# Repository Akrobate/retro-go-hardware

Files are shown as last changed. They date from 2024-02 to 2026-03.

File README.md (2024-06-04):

# retro-go-hardware

## Hardware for the RetroGo (ducalex)

Software for this hardware
https://github.com/Akrobate/retro-go

This is a fork of 
https://github.com/ducalex/retro-go

To be sure to have the most adapted version for now for this hardware use https://github.com/Akrobate/retro-go, but most recent version of firmware is on https://github.com/ducalex/retro-go. The author accepted my important updates so this harware should perfectly work with the original code.

## Construction log

You can see my [construction log](construction-log/README.md) with real device photos and steps

## Pieces for project

[List of all electronic and not electronics parts](electronic/README.md)

## Generate png previews

```bash
./generate_png_files.sh
```

Output files will be stored in `./png_files/`

## Generate png previews

```bash
./generate_stl_files.sh
```

Output files will be stored in `./stl_files/`

## Configurations

You can configure all projects params from `configurations/global.scad`.

## Main project

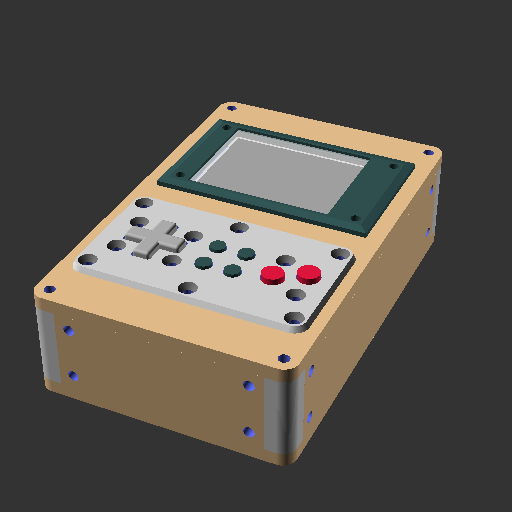
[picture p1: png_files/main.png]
RetroGoHarware main preview


## Components

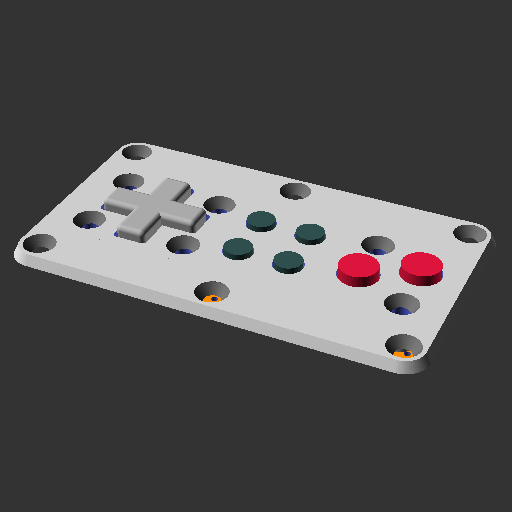
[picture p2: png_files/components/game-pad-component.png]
Gamepad controller

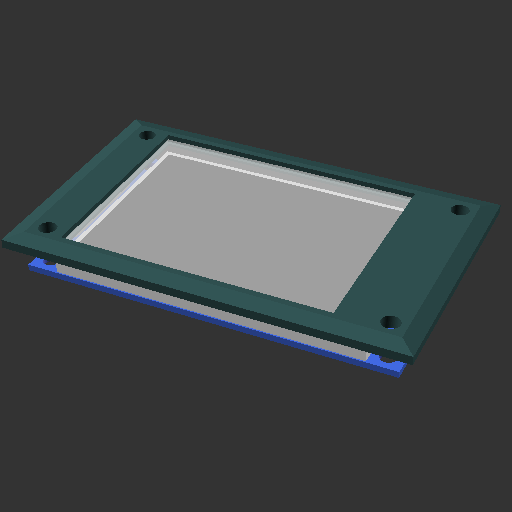
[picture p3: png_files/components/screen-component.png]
Screen

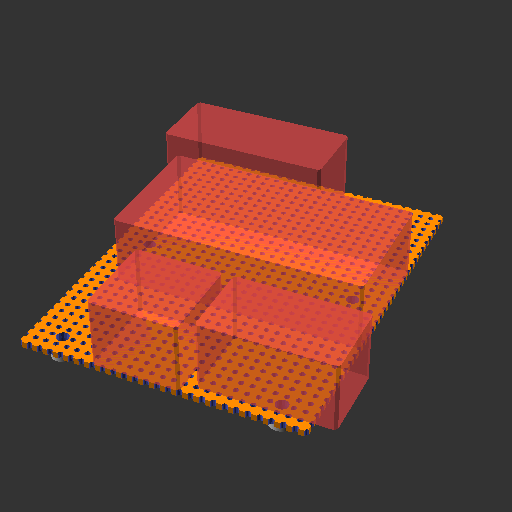
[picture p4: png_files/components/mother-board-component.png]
Mother board component

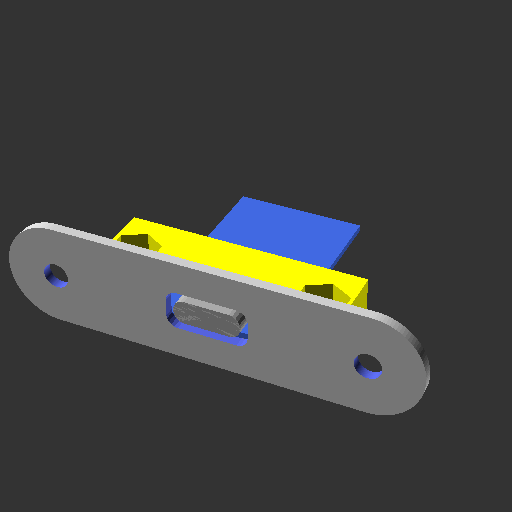
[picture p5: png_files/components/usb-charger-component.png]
USB Charger

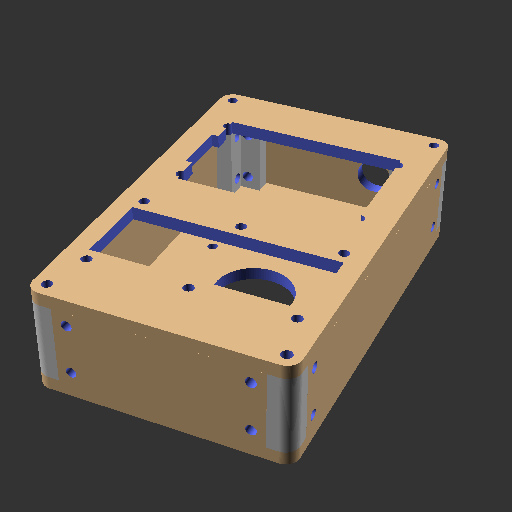
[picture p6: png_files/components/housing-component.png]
Housing

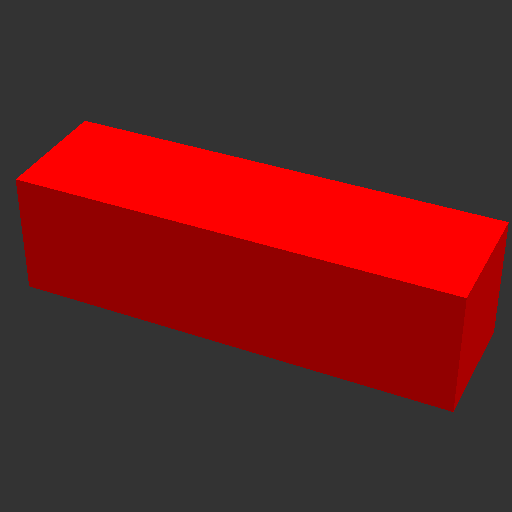
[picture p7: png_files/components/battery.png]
Battery


## Pieces

### Housing
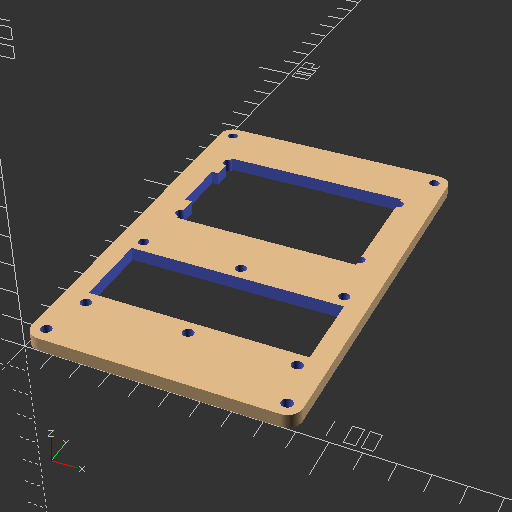
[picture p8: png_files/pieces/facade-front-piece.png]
facade-front-piece.scad

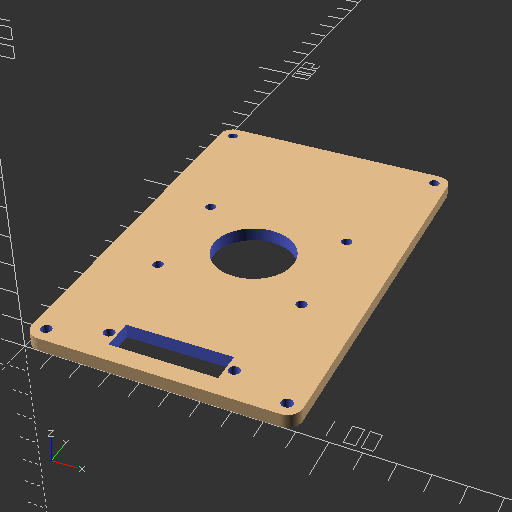
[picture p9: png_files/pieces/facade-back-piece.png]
facade-back-piece.scad

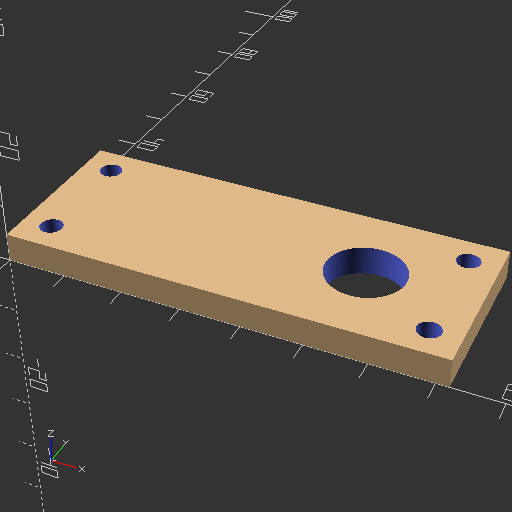
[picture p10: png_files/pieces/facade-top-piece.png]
facade-top-piece.scad

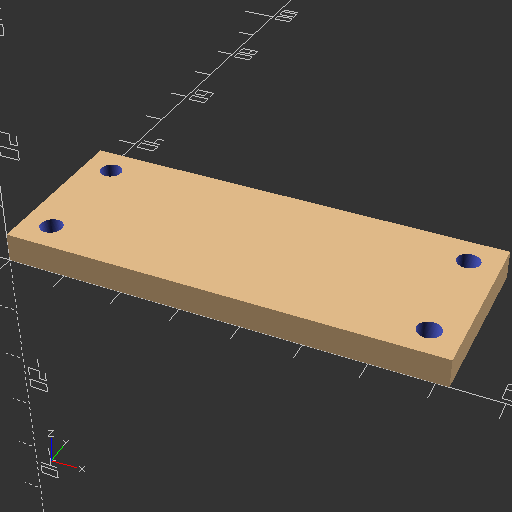
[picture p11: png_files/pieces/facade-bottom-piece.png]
facade-bottom-piece.scad

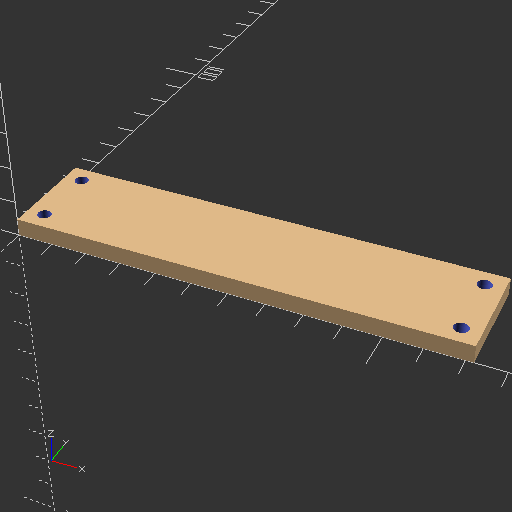
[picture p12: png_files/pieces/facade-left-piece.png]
facade-left-piece.scad

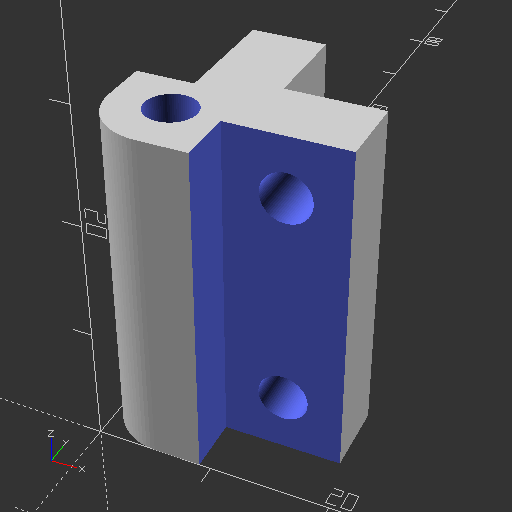
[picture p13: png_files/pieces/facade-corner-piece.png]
facade-corner-piece.scad


### Gamepad controller
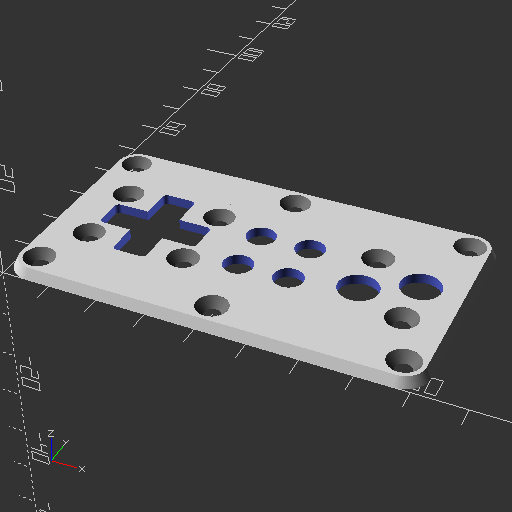
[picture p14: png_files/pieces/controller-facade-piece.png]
controller-facade-piece.scad

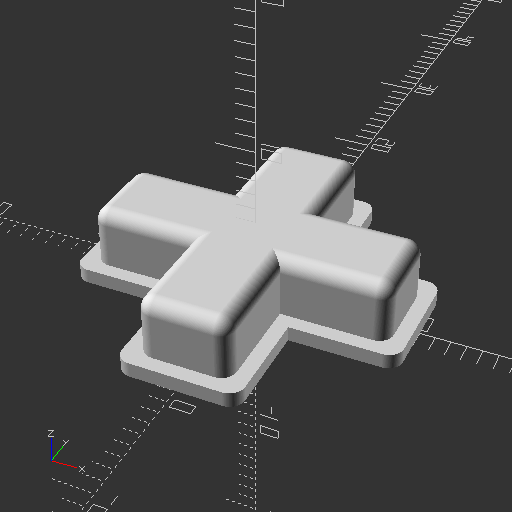
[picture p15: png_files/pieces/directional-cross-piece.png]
directional-cross-piece.scad

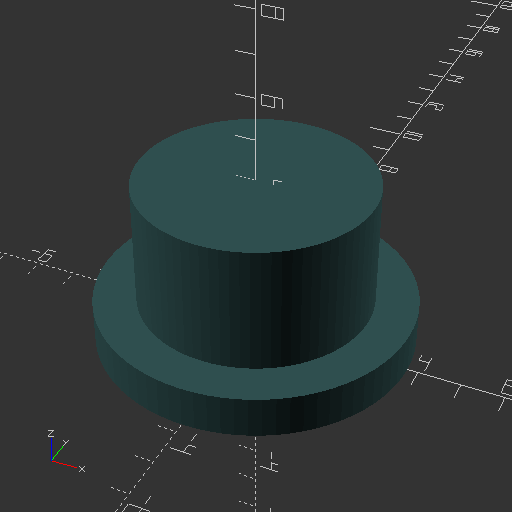
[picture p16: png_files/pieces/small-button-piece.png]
small-button-piece.scad

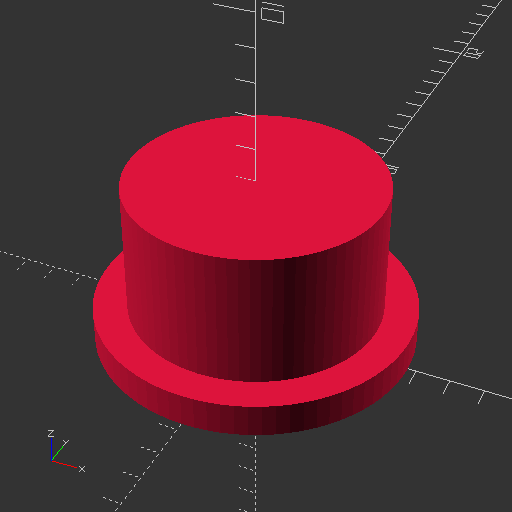
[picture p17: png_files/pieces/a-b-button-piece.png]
a-b-button-piece.scad

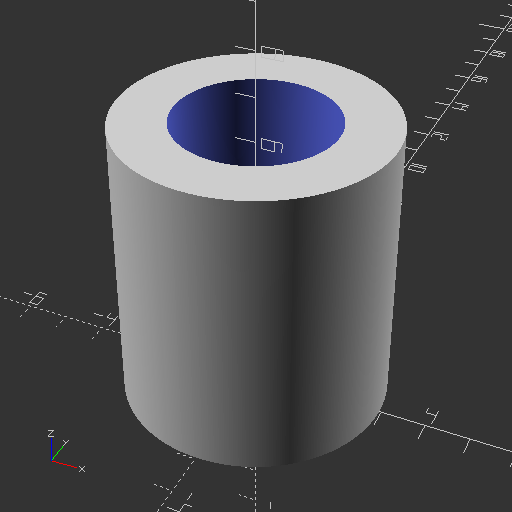
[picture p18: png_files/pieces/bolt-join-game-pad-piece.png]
bolt-join-game-pad-piece.scad


### Screen
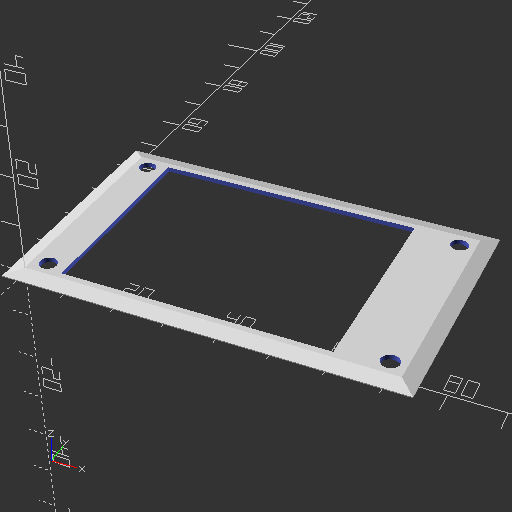
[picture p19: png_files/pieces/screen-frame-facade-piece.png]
screen-frame-facade-piece.scad

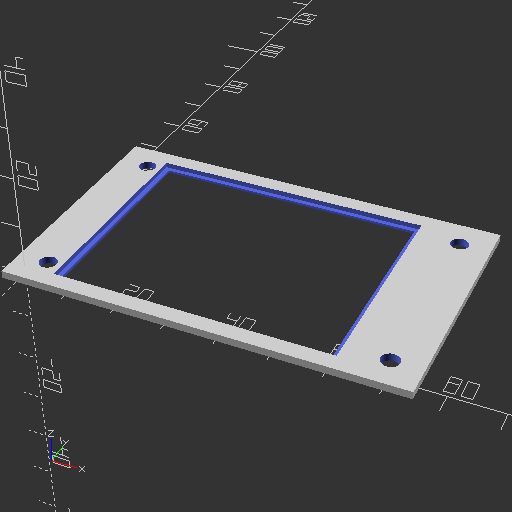
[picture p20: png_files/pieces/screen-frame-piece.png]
screen-frame-piece.scad

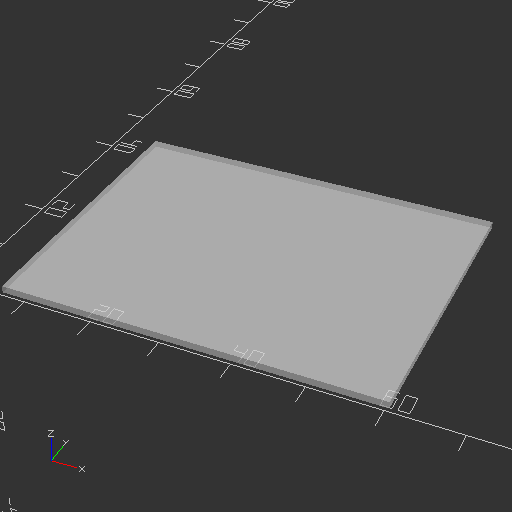
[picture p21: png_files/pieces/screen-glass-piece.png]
screen-glass-piece.scad


### Speaker
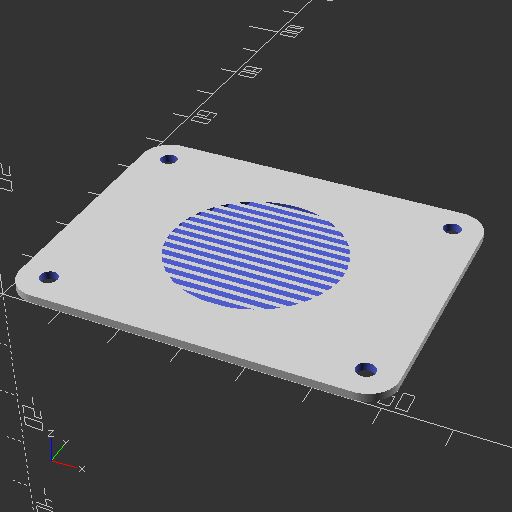
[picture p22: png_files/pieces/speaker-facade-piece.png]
speaker-facade-piece.scad


### USB Charger
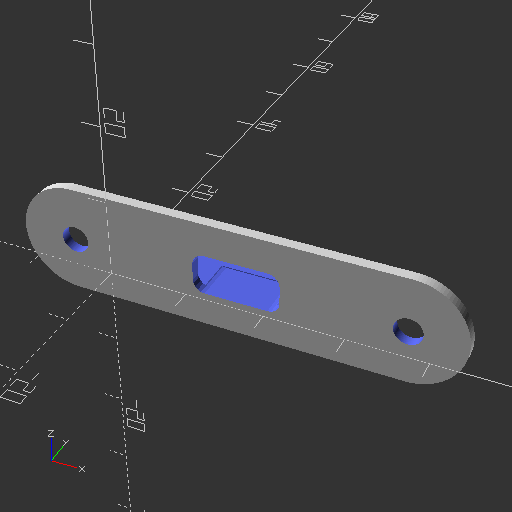
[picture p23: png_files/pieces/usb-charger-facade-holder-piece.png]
usb-charger-facade-holder-piece.scad

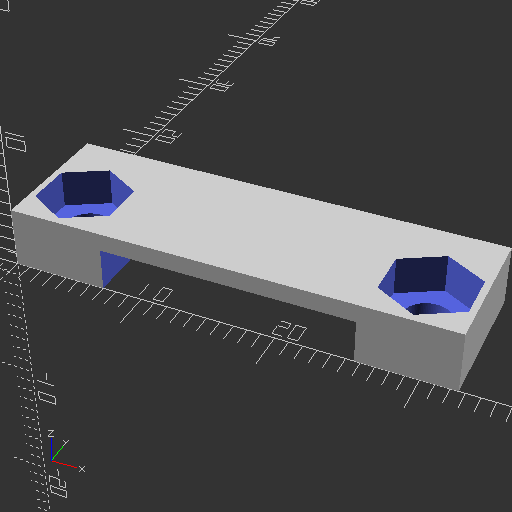
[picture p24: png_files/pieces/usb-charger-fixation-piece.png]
usb-charger-fixation-piece.scad


### Mother board

Mother board positionning components

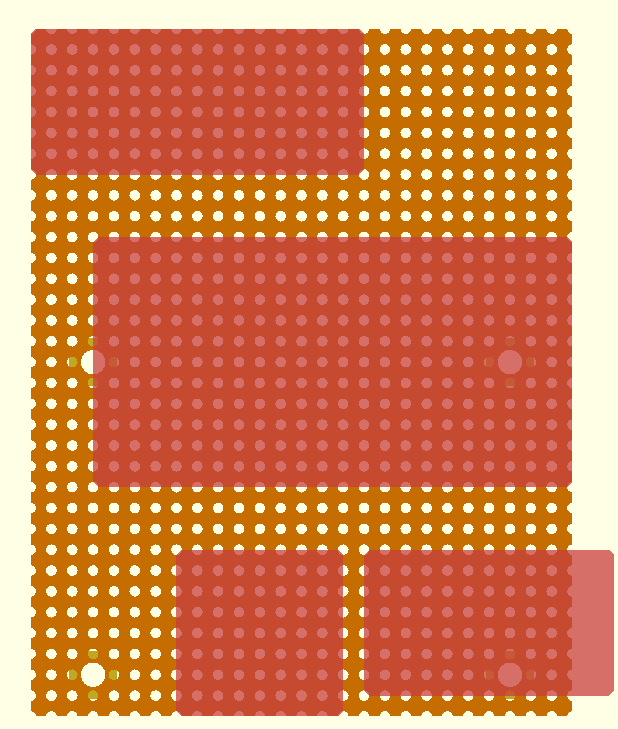
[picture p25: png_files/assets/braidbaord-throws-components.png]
Mother board positionning


Mother bard fixation throws

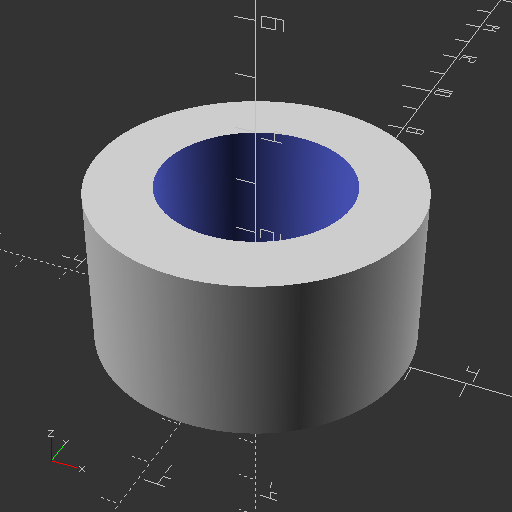
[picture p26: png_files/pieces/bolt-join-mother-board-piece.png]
bolt-join-mother-board-piece.scad


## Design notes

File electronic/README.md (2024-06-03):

# Electronic

## Electronic parts list

| Category | Product name | Price | Pieces | Unitary Price |
| :---| :--- |---:|---:|---:|
| Microcontroller| ESP32-S3 ESP32-S3-DevKitC-1 Cartes de Développement XTVTX 2 pièces ESP32 S3 WROOM-1-N16R8 Module 16M de mémoire Flash à Extension Externe 8M PSRAM avec WiFi, Bluetooth 5.0 pour Arduino | 26,99€ | 2 | 13,50€ |
| SD Card reader| Jopto 6 Pièces Mini Module de Carte SD Module d'extension de Stockage Micro SD Module de Lecteur de Carte Micro SD TF Adaptateur de Carte Compatible avec Arduino AVR Arm | 9,99€ | 6 | 1,67€ |
| Battery holder and charger| GTIWUNG 6 Pièces 3.7V 18650 Support de Batterie Boîtier en Plastique Boîte de Rangement avec Wire Leads + 10 Pièces Interface d'entrée de Type C USB 5V 1A 18650 Module de Chargeur de Batterie | 9,99€ | 6 | 1,67€ |
| Sound I2S module| Lot de 4 amplificateurs audio Max98357 I2S 3 W avec interface décodeur Dac I2S Classe D sans filtre | 16,99€ | 4 | 4,25€ |
| Speaker | Weewooday Petits Haut-Parleurs 2 W 8 ohms Haut-Parleur à Aimant Interne Rond à Coque Métallique Micro Haut-Parleur Interne pour Mini Haut-Parleurs, DVD, EVD, Mini Haut-Parleurs Multimédia | 9,99€ | 6 | 1,67€ |

## Bolts and buttons parts list

| Category | Product name | Price | Pieces | Unitary Price |
| :---| :--- |---:|---:|---:|
| On/Off button | Gebildet 4pcs 12mm 3A 12V/24V/125V/250V AC Autobloquant Interrupteur Bouton Poussoir Étanche en Cuivre Nickelé on Off Bouton-Poussoir Interrupteur(Tête Haute) dsqdqsd | 8,99€ | 4 | 2,25€
| Screen glass | Langaelex 10 pièces 178 x 127 x 1mm Plaque Acrylique Transparente Plaque Plexiglas Transparent pour le Remplacement du Verre du Cadre Photo, l'affichage des Projets, la Peinture (5 * 7 pouces) | 9,99€ | 10 | 0,99€ |
| Controller buttons | Youmile 100Pcs Tact Button Switch 2 Broches DIP 6x6x5mm PCB Momentary Tactile Tact Push Button Switch | 6,59€ | 100 | 0,07€ |
| Bolts | 440 pièces vis à tête creuse M3, vis à tête cylindrique, kit en acier inoxydable avec écrous, avec rondelles et 2 clés | 11,99 | 440 | 0.03€ |
| Bolts|KBRAKSI 720 Pièces Vis M3 Visserie Écrous et Boulons Vis à Tête Hexagonale Vis Mécaniques à Tête Fraisée Hex Socket Head Cap Vis Boulons Kit 4 mm 6 mm 8 mm 10 mm 12 mm Noir M3 Vis | 13,99€ | 720 | 0,02 |
| Bolts | AIEX 100pcs Écrous à Encastrer pour Impression 3D, Insert Fileté Laiton M3 Écrous en Laiton Moletés à Filetage Femelle Écrous Thermique pour Impression 3D Loptop Automobile Coque en Plastique | 9,19€ | 100 | 0,09€ |

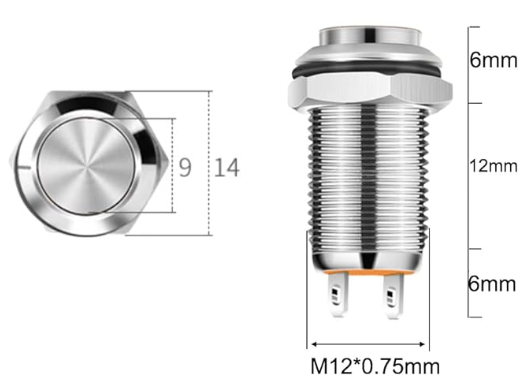
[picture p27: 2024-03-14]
3D-models/assets/on-off-button/on-off-button-preview.png

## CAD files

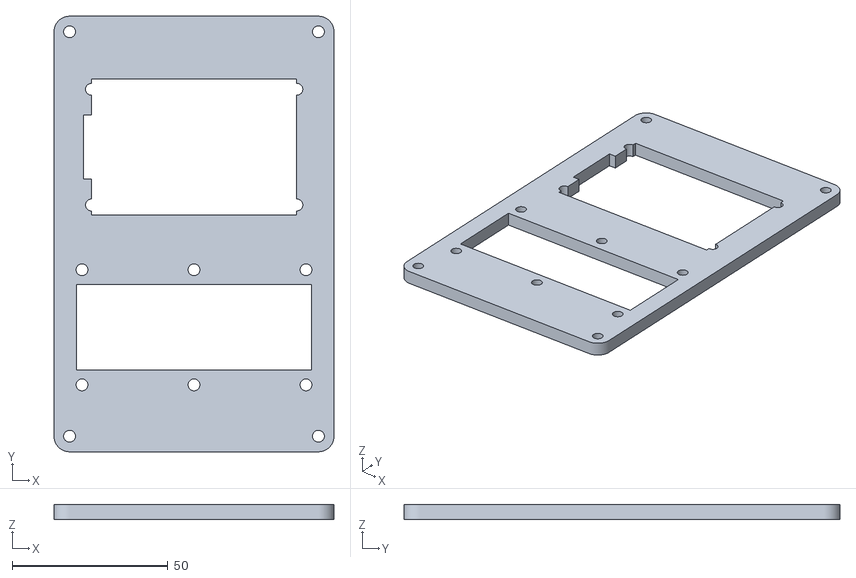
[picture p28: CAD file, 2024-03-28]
stl_files/facade-front-piece.stl
90.0 x 140.0 x 4.80

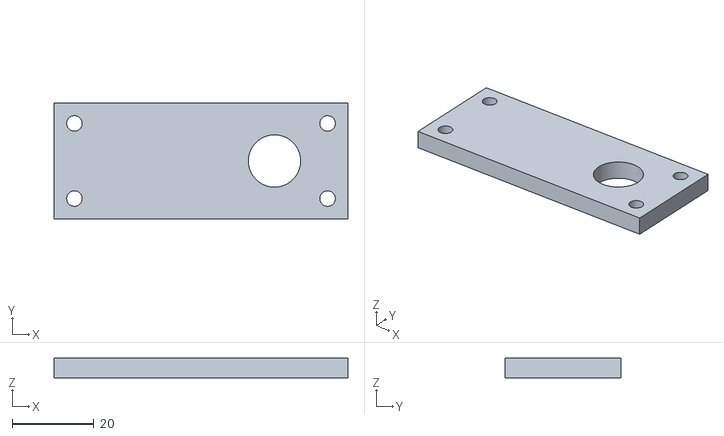
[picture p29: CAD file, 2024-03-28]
stl_files/facade-top-piece.stl
72.0 x 28.4 x 4.80

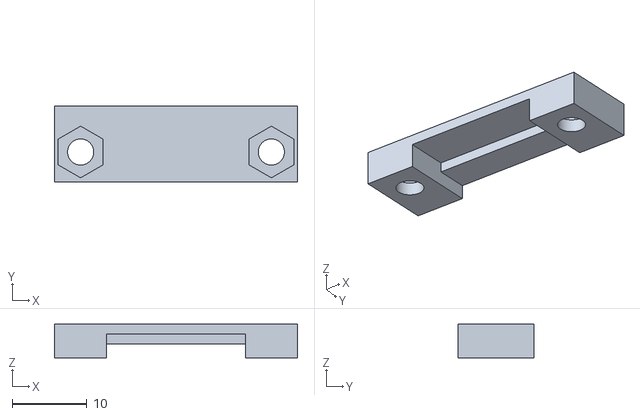
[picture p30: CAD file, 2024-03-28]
stl_files/usb-charger-fixation-piece.stl
32.6 x 10.1 x 4.50

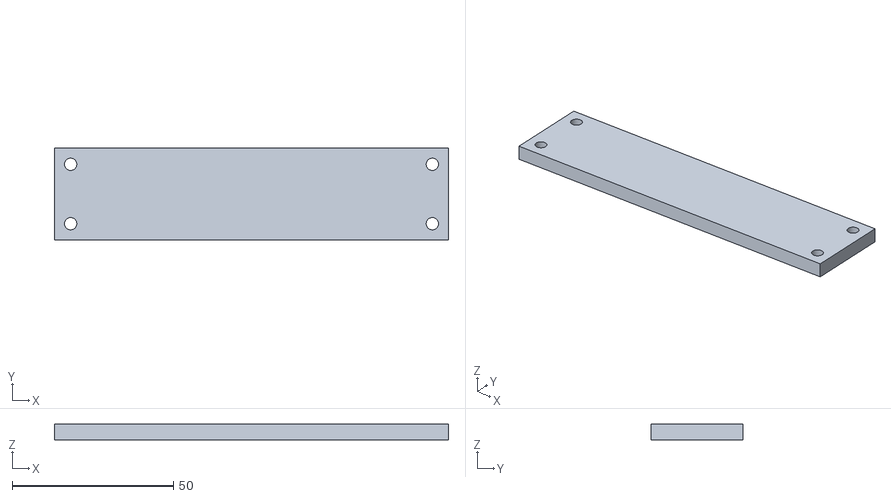
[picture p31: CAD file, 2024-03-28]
stl_files/facade-left-piece.stl
122.0 x 28.4 x 4.80

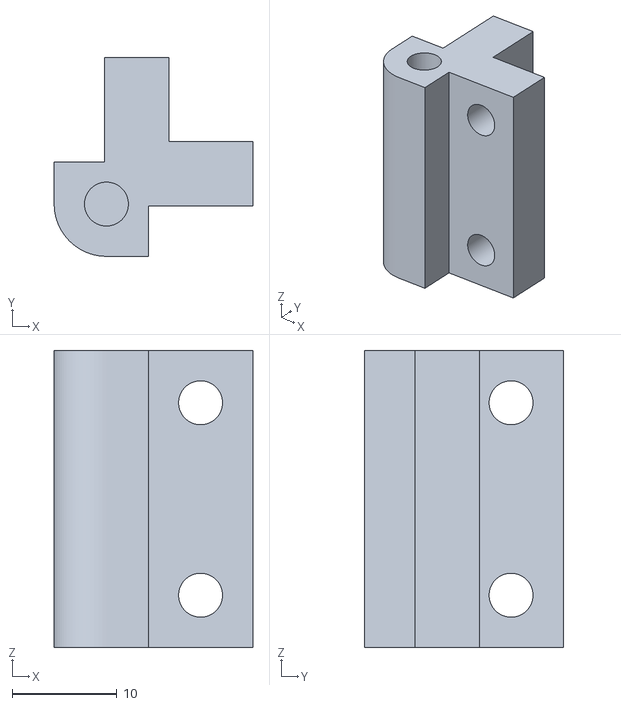
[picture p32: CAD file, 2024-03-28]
stl_files/facade-corner-piece.stl
19.0 x 19.0 x 28.4

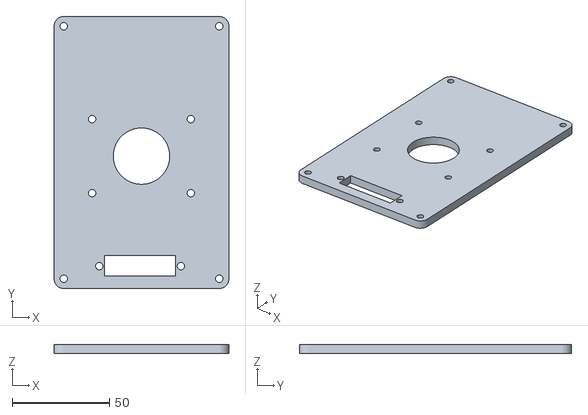
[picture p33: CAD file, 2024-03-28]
stl_files/facade-back-piece.stl
90.0 x 140.0 x 4.80

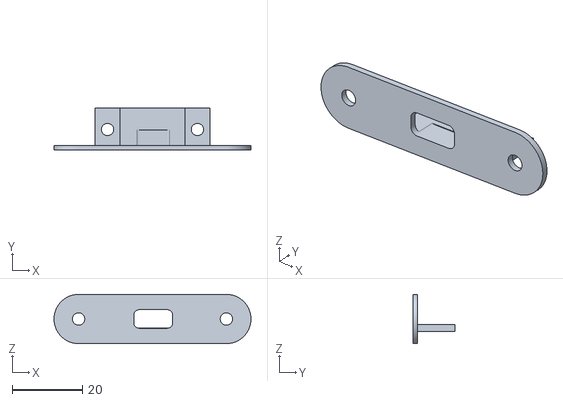
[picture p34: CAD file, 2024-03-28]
stl_files/usb-charger-facade-holder-piece.stl
56.0 x 12.0 x 14.0

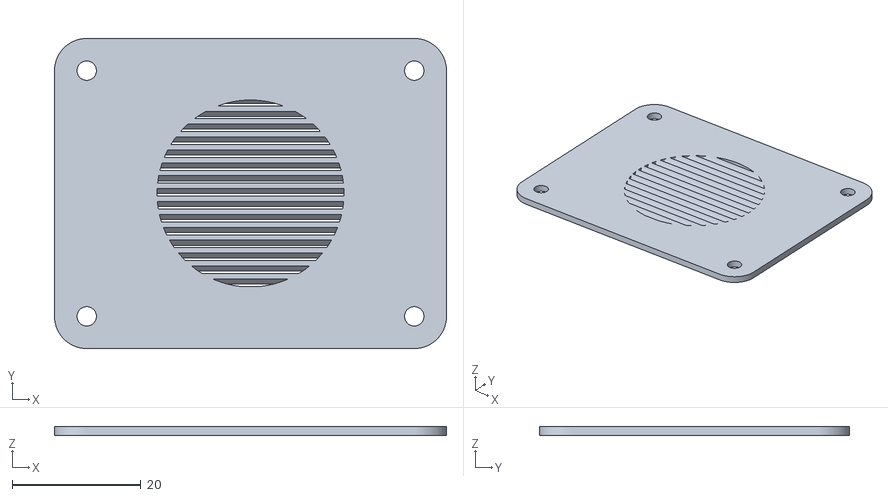
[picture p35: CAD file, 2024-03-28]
stl_files/speaker-facade-piece.stl
60.8 x 48.1 x 1.36

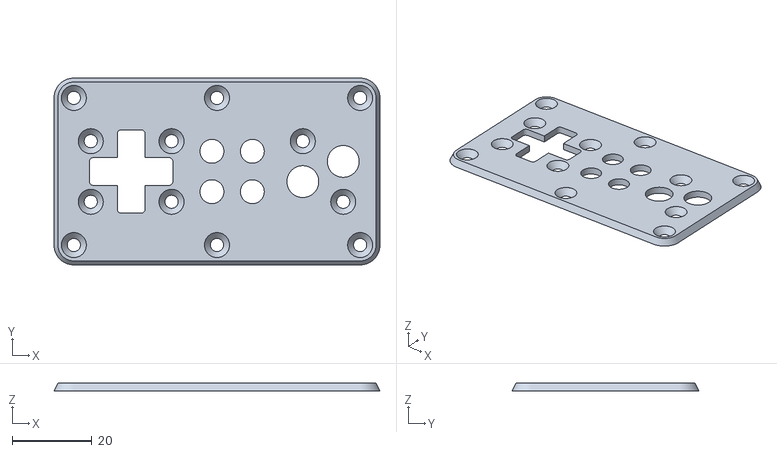
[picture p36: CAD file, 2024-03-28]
stl_files/controller-facade-piece.stl
82.0 x 47.0 x 2.00

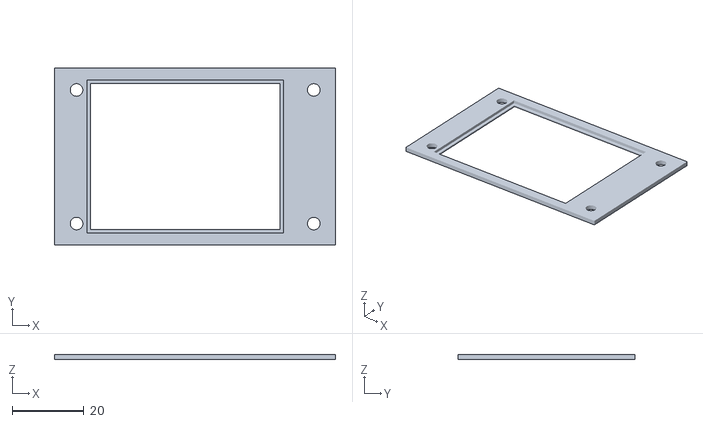
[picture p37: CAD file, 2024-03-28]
stl_files/screen-frame-piece.stl
78.2 x 49.2 x 1.50

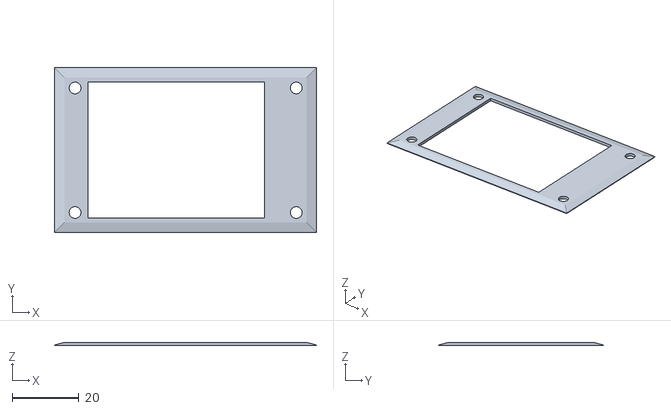
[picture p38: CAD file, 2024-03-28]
stl_files/screen-frame-facade-piece.stl
78.2 x 49.2 x 1.00

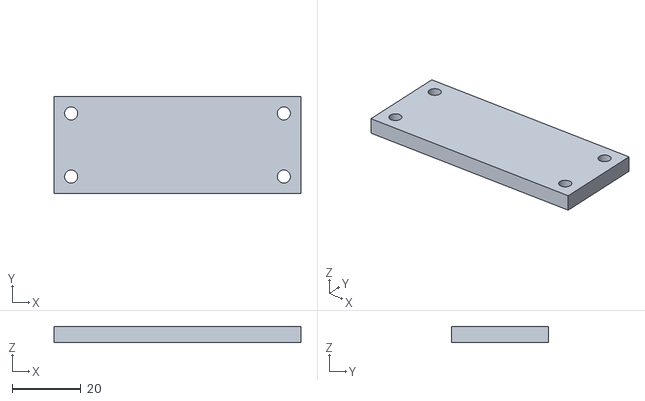
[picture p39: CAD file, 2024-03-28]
stl_files/facade-bottom-piece.stl
72.0 x 28.4 x 4.80

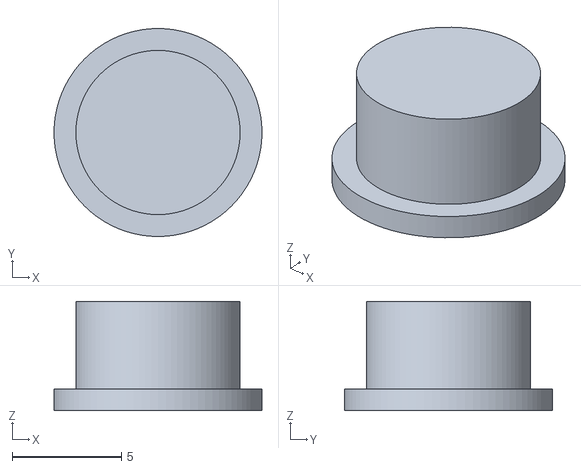
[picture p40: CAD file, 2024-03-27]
stl_files/a-b-button-piece.stl
9.50 x 9.50 x 5.00

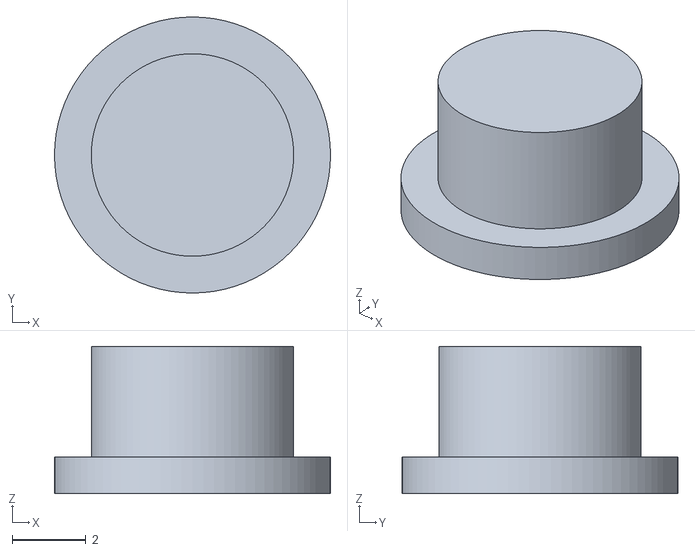
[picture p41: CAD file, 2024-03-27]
stl_files/small-button-piece.stl
7.50 x 7.50 x 4.00

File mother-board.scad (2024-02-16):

use <./pieces/subpieces/breadboard.scad>
use <./libraries/electronics.scad>



module motherBoard() {



    module dacModule() {
        x_points = 7;
        y_points = 7;

        support_z_size = 0; // 2.5

        color("Green")
        translate([0, 0, support_z_size])
            hull() {
                breadboard(
                    x_points = x_points,
                    y_points = y_points,
                    z_size = 7.1 - support_z_size,
                    draw_throws = false,
                    $fn = 16
                );
            }

    }



    module sdCardModule() {
        x_points = 6;
        y_points = 11;

        support_z_size = 0; // 2.5

        color("Green")
        translate([0, 0, support_z_size])
            hull() {
                breadboard(
                    x_points = x_points,
                    y_points = y_points,
                    z_size = 7.1 - support_z_size,
                    draw_throws = false,
                    $fn = 16
                );
            }
    }



    module esp32s3() {

        y_points = 22;
        x_points = 11;

        support_z_size = 0; // 2.5

        color("Green")
        translate([0, 0, support_z_size])
            hull() {
                breadboard(
                    x_points = x_points,
                    y_points = y_points,
                    z_size = 7.1 - support_z_size,
                    draw_throws = false,
                    $fn = 16
                );
            }
    }


    module dc2dc() {

        x_points = 6;
        y_points = 15;

        support_z_size = 0; // 2.5

        color("Green")
        translate([0, 0, support_z_size])
            hull() {
                breadboard(
                    x_points = x_points,
                    y_points = y_points,
                    z_size = 7.1 - support_z_size,
                    draw_throws = false,
                    $fn = 16
                );
            }
    }


    breadboard(
        x_points = 32,
        y_points = 25,
        draw_throws = false,
        $fn = 16
    );

    translate([0, 0, 1.5]) {
        translateBreadboard(11, 0)
            esp32s3();

        translateBreadboard(2, 0)
            sdCardModule();

        translateBreadboard(2, 14)
            dacModule();

        translateBreadboard(26, 4)
            dc2dc();     
    }
}


motherBoard();

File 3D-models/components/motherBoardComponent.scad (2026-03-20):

include <../configurations/global.scad>

use <../openscad_modules/breadboard/breadboard.scad>
use <../pieces/boltJoinMotherBoardPiece.scad>

use <../openscad_modules/commons/forEachCoord.scad>


/**
 * motherBoardComponent
 * @name motherBoardComponent
 * @description Mother board component
 * @type component
 * @parent root
 */
module motherBoardComponent(
    mother_board_bolt_throws_list = mother_board_bolt_throws_list,
    mother_board_x_size_point = mother_board_x_size_point,
    mother_board_y_size_point = mother_board_y_size_point,
    draw_throws = false
) {

    module dacModule(z_size = 16) {
        genericModule(z_size = z_size, x_points = 7, y_points = 7, color = "FireBrick");
    }

    module sdCardModule(z_size = 16) {
        genericModule(z_size = z_size, x_points = 11, y_points = 6, color = "RoyalBlue");
    }

    module esp32s3(z_size = 16) {
        genericModule(z_size = z_size, x_points = 22, y_points = 11, color = "DarkSlateGray");
    }

    module dc2dc(z_size = 16) {
        genericModule(z_size = z_size, x_points = 15, y_points = 6, color = "RoyalBlue");
    }

    breadboard(
        x_points = mother_board_x_size_point,
        y_points = mother_board_y_size_point,
        throw_3mm_coord_list = mother_board_bolt_throws_list,
        draw_throws = draw_throws, $fn = 16
    );


    module electronicModules() {
        translateBreadboard(3, 11)
            esp32s3();

        translateBreadboard(16, 1)
            sdCardModule();

        translateBreadboard(7, 0)
            dacModule();

        translateBreadboard(0, 26)
            dc2dc();
    }

    #translate([0, 0, 1.5])
        electronicModules();

        forEachCoord([
            for (i = mother_board_bolt_throws_list) [
                i[0] * getPointSize(),
                i[1] * getPointSize(),
                -bolt_join_mother_board_height
            ]
        ])
            boltJoinMotherBoardPiece();
}


/**
 * @png
 * @colorscheme BeforeDawn
 * @view axes,scales
 */
motherBoardComponent(
    draw_throws = true
);

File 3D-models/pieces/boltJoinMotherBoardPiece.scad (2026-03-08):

include <../configurations/global.scad>

/**
 * boltJoinMotherBoardPiece
 * @name boltJoinMotherBoardPiece
 * @description Joins to hold mother board
 * @type piece
 * @parent motherBoardComponent
 */
module boltJoinMotherBoardPiece(
    internal_diameter = bolt_join_mother_board_internal_diameter,
    external_diameter = bolt_join_mother_board_external_diameter,
    height = bolt_join_mother_board_height,
    _fn = bolt_join_fn
) {
    difference() {
        cylinder(d = external_diameter, h = height, center = false, $fn = _fn);

        translate([0,0,-0.1])
            cylinder(d = internal_diameter, h = height * 2 + 0.1 * 2, center = false, $fn = _fn);
    }
}

/**
 * @stl
 * @png
 * @colorscheme BeforeDawn
 * @view axes,scales
 */
boltJoinMotherBoardPiece();

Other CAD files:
stl_files/screen-glass-piece.stl
stl_files/directional-cross-piece.stl
stl_files/bolt-join-game-pad-piece.stl
stl_files/bolt-join-mother-board-piece.stl
3D-models/assets/lcd-screen/configurations.scad
3D-models/assets/lcd-screen/screen.scad
3D-models/assets/on-off-button/on-off-button.scad
3D-models/assets/roundButton/configurations.scad
3D-models/assets/roundButton/roundButton.scad
3D-models/assets/speaker-28mm/configurations.scad
3D-models/assets/speaker-28mm/speaker-28mm.scad
3D-models/assets/usb-charger/configurations.scad
3D-models/assets/usb-charger/usb-charger.scad
3D-models/components/gamePadComponent.scad
3D-models/components/housingComponent.scad
3D-models/components/screenComponent.scad
3D-models/components/usbChargerComponent.scad
3D-models/configurations/global.scad
3D-models/enveloppes/bolt.scad
3D-models/enveloppes/onOffButtonThrowEnveloppe.scad
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

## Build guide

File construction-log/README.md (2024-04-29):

# Construction log

### Electronic Schematic

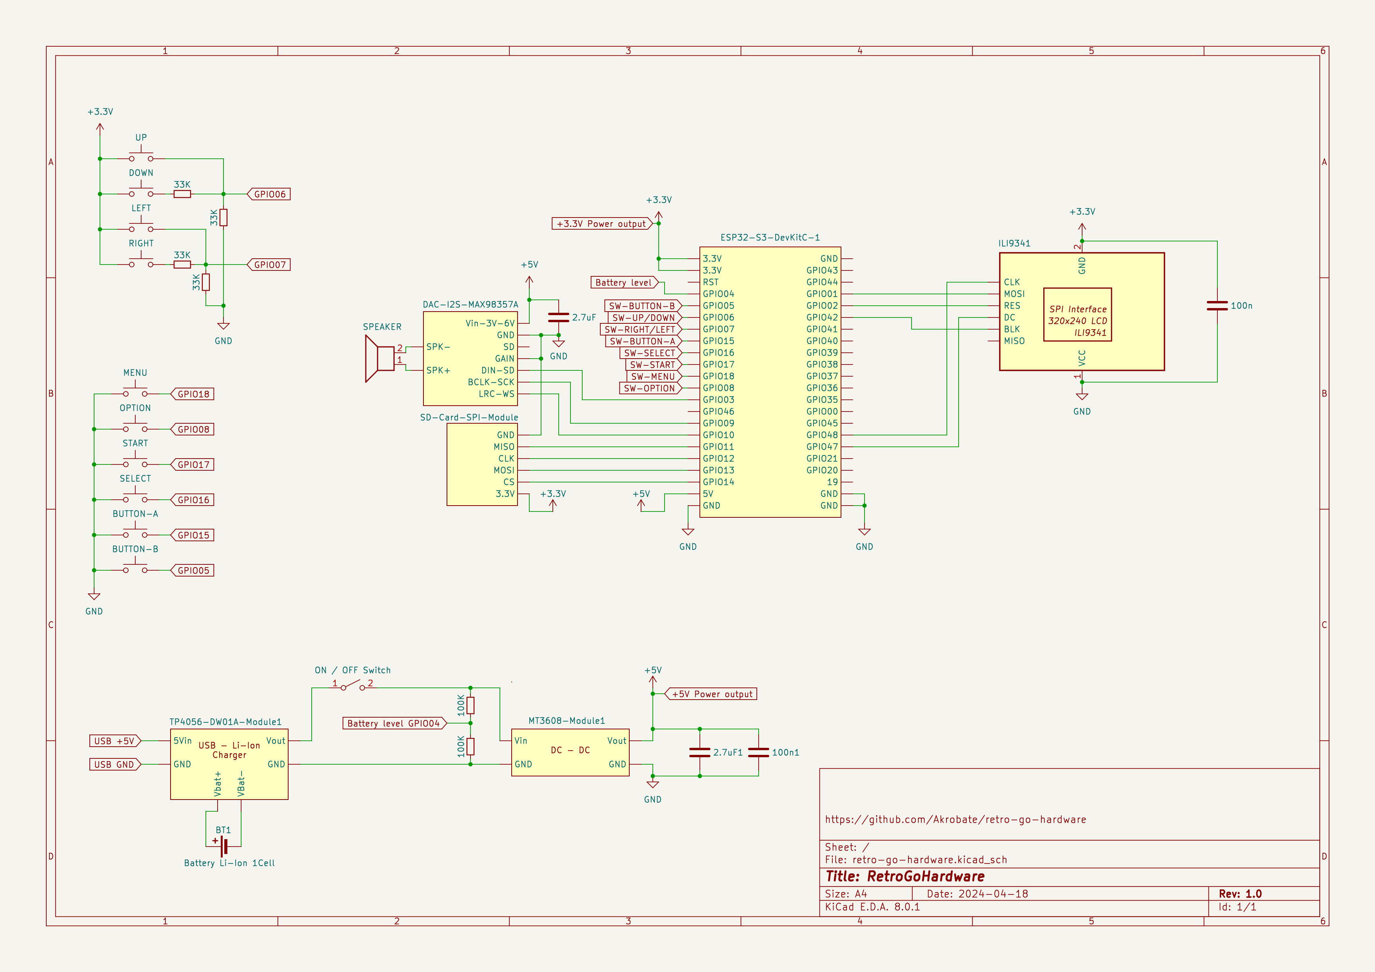
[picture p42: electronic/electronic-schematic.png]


### Electronic prototyping

<p float="left">
  
  
</p>

<p float="left">
  
  
</p>

### Front facade

<p float="left">
  
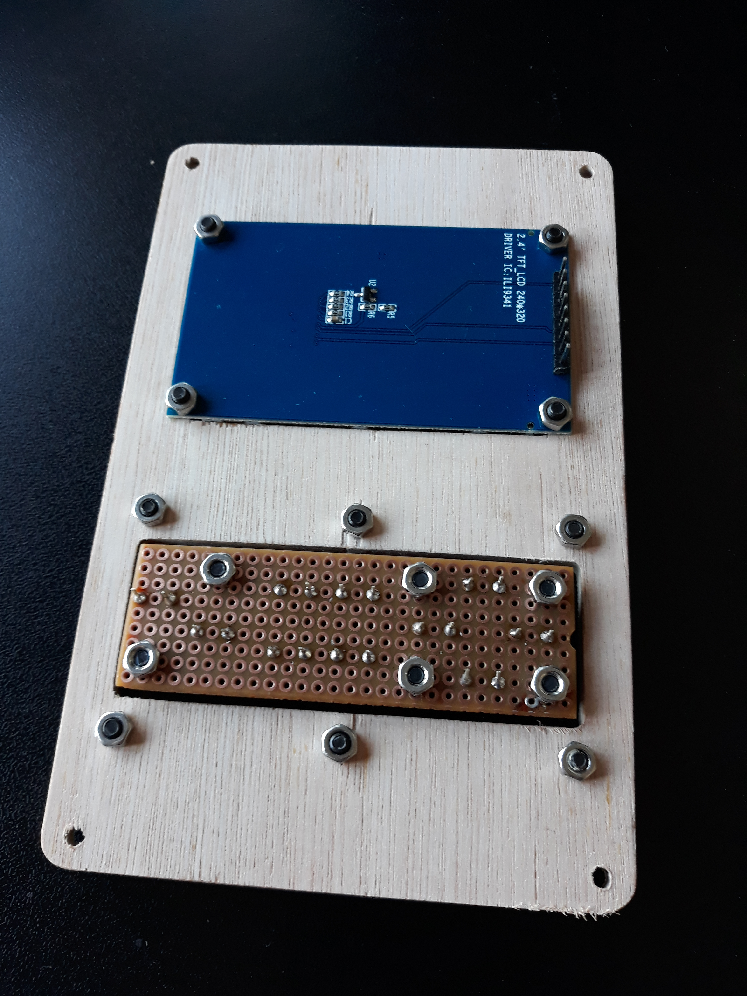
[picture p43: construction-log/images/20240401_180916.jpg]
  
</p>

### Controller

<p float="left">
  
  
</p>

### Controller Electronics

<p float="left">
  
  
</p>

### Motherboard
<p float="left">
  
  
</p>

### Mounting
<p float="left">
  
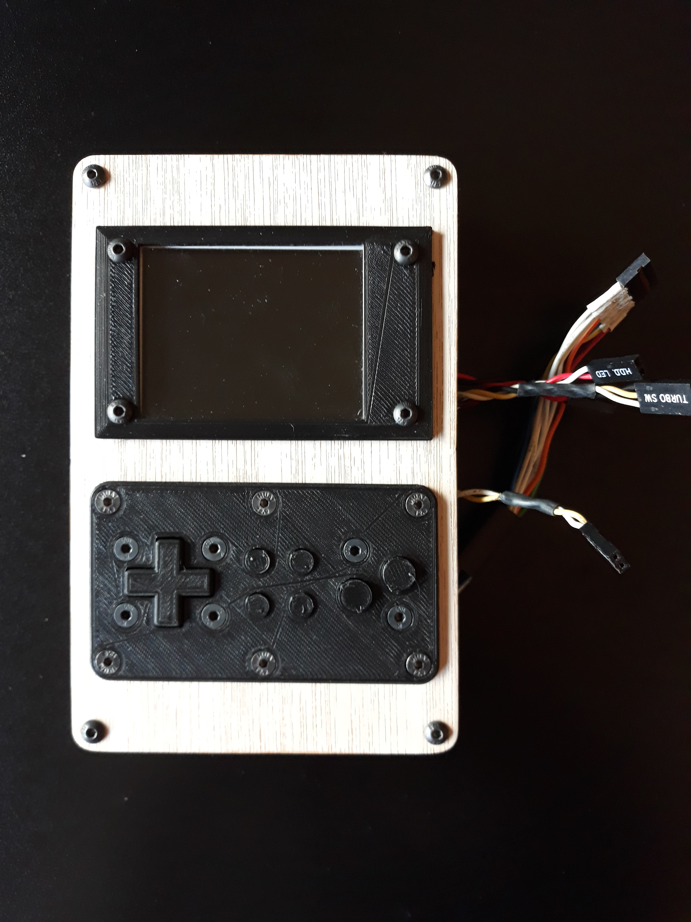
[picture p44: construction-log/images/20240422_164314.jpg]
  
</p>
<p float="left">
  
  
</p>
<p float="left">
  
  
</p>

### Housing

<p float="left">
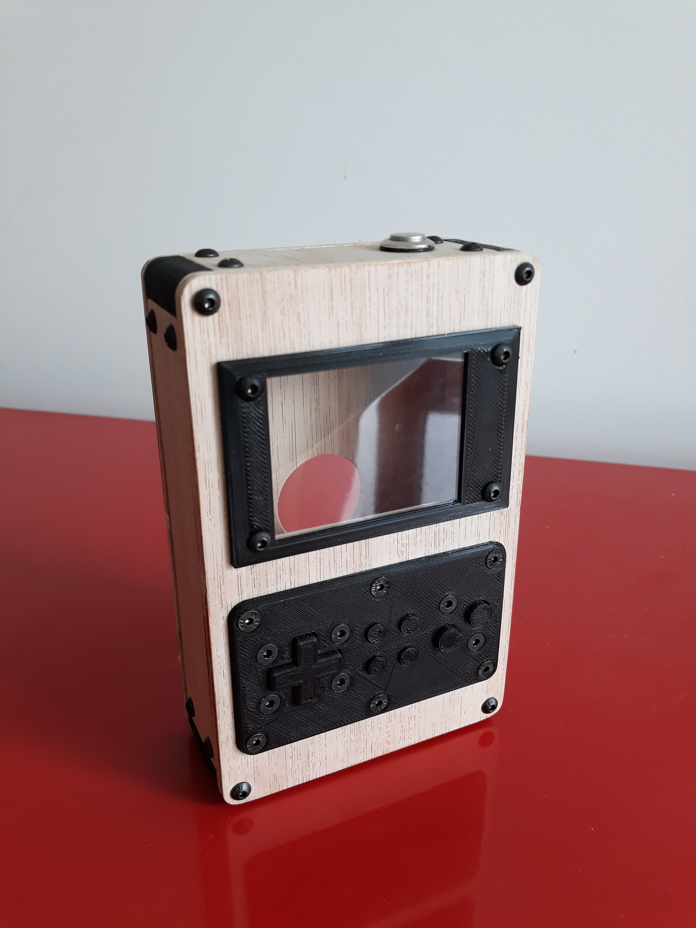
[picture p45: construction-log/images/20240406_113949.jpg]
  
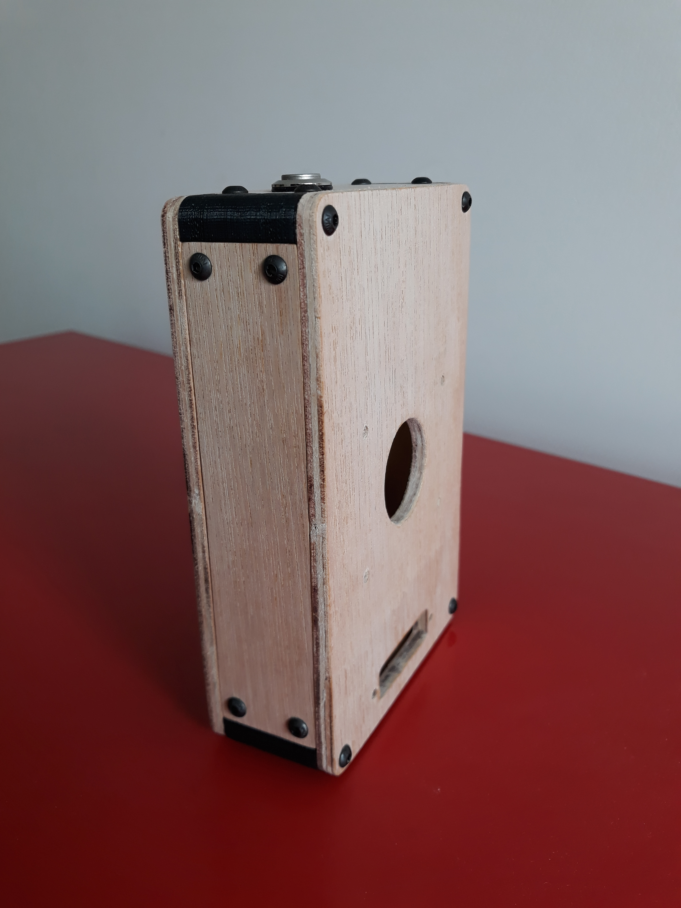
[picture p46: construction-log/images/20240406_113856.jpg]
  
</p>

<p float="left">
  
  
</p>

<p float="left">
  
  
</p>

### Screen

<p float="left">
  
  
</p>

### Speaker

<p float="left">
  
</p>

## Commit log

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2024-02-09 Directional cross piece added
    [directional-cross-piece.scad]
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2024-02-10 Fixed directionnal cross height
    [directional-cross-piece.scad]
2024-02-10 Working on sd card holder
    [sdcard-holder-piece.scad]
2024-02-10 Fixed size
    [main.scad]
2024-02-10 Added stl files folder
    [directional-cross-facade.stl, directional-cross-piece.stl, sdcard-holder-piece.stl]
2024-02-11 Working on proto of controller
    [proto.scad]
2024-02-11 updated sizes for the facade
    [main.scad]
2024-02-11 Added generic small button
    [small-button-piece.scad]
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2024-02-11 Added new version of facade
    [controller-breadboard-facade.scad]
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2024-02-12 Added cross piece configuration
    [directional-cross-piece.scad]
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2024-02-13 Added fixes
    [controller-breadboard-facade.scad, controller-facade-piece.scad, game-pad-component.scad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]
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2024-02-15 Working on facade front
    [global.scad, proto.scad]
2024-02-15 Added libraries generic function
    [facade-top.scad]
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2024-02-15 Updated with new vars
    [game-pad-component.scad, global.scad]
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2024-02-16 Added mother board draft component
    [mother-board.scad]
2024-02-16 Added facade buttom piece
    [facade-bottom.scad]
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2024-02-18 Fixed corners
    [facade-corner.scad, global.scad, proto.scad]
2024-02-18 Finished housing box, created component
    [facade-corner.scad, global.scad, housing-component.scad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]
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2024-02-20 Fixed namings
    [facade-back-piece.scad, facade-front-piece.scad, facade-left-piece.scad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]
2024-02-20 Working on screen throws
    [main.scad, proto.scad]
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2024-02-21 Working on screen embedding
    [proto.scad, screen.scad]
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2024-02-22 Added piece x / y branches configuration
    [facade-corner-piece.scad]
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2024-02-24 Fixed parameters in pieces
    [facade-front-piece.scad, global.scad, screen-frame-facade-piece.scad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]
2024-02-24 Added fixations throws diameters
    [facade-front-piece.scad, global.scad]
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2024-02-25 Added screen to the design
    [facade-front-piece.scad, game-pad-component.scad, global.scad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]
2024-02-25 Fixed throws sizes
    [facade-front-piece.scad, main.scad]
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2024-02-27 Added usb charger asset
    [proto.scad, usb-charger.scad]
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2024-02-28 Added speaker asset, work in progress
    [configuration.scad, speaker-28mm.scad]
2024-02-28 Finished speaker asset, added config to the usb-charger
    [configuration.scad, speaker-28mm.scad, usb-charger.scad]
2024-02-29 Preparing working space on usb charger
    [configurations.scad, usb-charger-component.scad, usb-charger.scad]
2024-03-01 Working on esp holder
    [usb-charger-component.scad]
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2024-03-02 Working on usb charger holder
    [facade-corner-piece.stl, screen-frame-piece.stl, usb-charger-component.proto_1.scad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]
2024-03-03 Working on charger handler
    [configurations.scad, usb-charger-component.scad, usb-charger.scad]
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2024-03-03 Added rendered screen frame facade
    [screen-frame-facade-piece.stl]
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2024-03-05 Fine tuning usb charger holder
    [global.scad, main.scad, mother-board-component.scad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]
2024-03-06 Positioned usb chargeer, added usb charger throw
    [facade-back-piece.scad, global.scad, housing-component.scad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]
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2024-03-12 Generated housing preview documentation
    [usb-charger-component.scad]
2024-03-14 Added button on off
    [facade-top-piece.scad, global.scad, housing-component.scad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]
2024-03-15 Added facade bottom piece
    [facade-bottom-piece.scad, housing-component.scad, main.scad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]
2024-03-16 Fixed on of button throw, working on speaker enveloppe
    [configurations.scad, facade-top-piece.scad, main.scad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]
2024-03-16 Working on mother board fixation
    [boldJoinPiece.scad, breadboard.scad, facade-back-piece.scad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]
2024-03-17 WOrring on speaeker facade
    [bolt-join-piece.scad, facade-back-piece.scad, facade-top-piece.scad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]
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2024-03-19 Added bolt join game pad
    [bolt-join-game-pad-piece.scad, bolt-join-mother-board-piece.scad, game-pad-component.scad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]
2024-03-21 Cleaning repository, updated png generation
    [usb-charger-component.proto_1.scad, usb-charger-component.scad]
2024-03-22 Enlarged controller braidboard throw
    [facade-front-piece.scad, global.scad]
2024-03-23 Fixing external housing thorws diameter to 3.8
    [facade-front-piece.scad, facade-left-piece.scad, global.scad]
2024-03-24 Fixed specification of throws diameter on housing
    [facade-back-piece.scad, facade-bottom-piece.scad, facade-top-piece.scad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]
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2024-03-26 Updated buttons a,b and small diameter
    [controller-facade-piece.scad, game-pad-component.scad, global.scad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]
2024-03-27 Ajusted bolt z size
    [a-b-button-piece.stl, bolt-join-game-pad-piece.scad, bolt-join-game-pad-piece.stl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]
2024-03-28 Fixed bottom piece
    [bolt-join-game-pad-piece.stl, bolt-join-mother-board-piece.stl, controller-facade-piece.stl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]
2024-03-30 Documented, cleaned project, removed sdcard holder
    [sdcard-holder-piece.scad, sdcard-holder-piece.stl]
2024-03-31 Added comments to sizes
    [facade-back-piece.scad, facade-bottom-piece.scad, facade-left-piece.scad]
2024-04-02 Rotated usb pieces optimised for printing
    [usb-charger-facade-holder-piece.scad, usb-charger-fixation-piece.scad]
2024-04-06 Added facade corner length correction
    [facade-corner-piece.scad, global.scad]
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2024-04-08 Tested to fix glitches, added new global param
    [facade-corner-piece.scad, global.scad]
2024-04-09 Added KiCad init project
    [retro-go-hardware.kicad_sch]
2024-04-10 Added components to the library
    [retro-go-hardware.kicad_sch]
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2024-04-12 Added I2S module to schematic
    [retro-go-hardware.kicad_sch]
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2024-04-15 Fixed component in library, added speaker
    [retro-go-hardware.kicad_sch]
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2024-04-19 Added battery level probe
    [retro-go-hardware.kicad_sch]
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2024-05-03 Moved electronic files to electronic folder
    [retro-go-hardware.kicad_sch]
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2024-05-14 Documenting modules charger usb
    [usb-charger-component.scad, usb-charger-facade-holder-piece.scad, usb-charger-fixation-piece.scad]
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2024-05-18 Added comments in subpieces
    [round-button.scad, rounded-cube.scad, rounded-pane.scad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]
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2024-05-22 Added comments to simple assets
    [speaker-28mm.scad, usb-charger.scad]
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2024-05-26 Added enveloppes call for rendering
    [on-off-button-throw-enveloppe.scad, screen-enveloppe.scad, usb-c-connector-enveloppe.scad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]
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2025-05-15 3D micro code cleaen
    [bolt.scad]
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2025-12-14 Added breadboard to assets instead of submodule
    [breadboard.scad, controller-breadboard-facade.scad, directional-cross-facade.scad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]
2025-12-17 Moved battery to assets
    [battery.scad, main.scad]
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2025-12-21 Added round button to assets
    [configurations.scad, roundButton.scad]
2026-02-10 Fixed usage of global vars
    [game-pad-component.scad, global.scad, mother-board-component.scad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]
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2026-03-15 Fixed naming in subpieces
    [abButtonPiece.scad, controllerBreadboardFacade.scad, controllerFacadePiece.scad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]
2026-03-16 Fixed enveloppe naming
    [facadeBackPiece.scad, facadeFrontPiece.scad, facadeTopPiece.scad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]
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
